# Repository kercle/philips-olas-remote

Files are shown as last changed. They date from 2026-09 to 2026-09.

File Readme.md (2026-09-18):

# Controller for Philips Olas Ceiling Fan

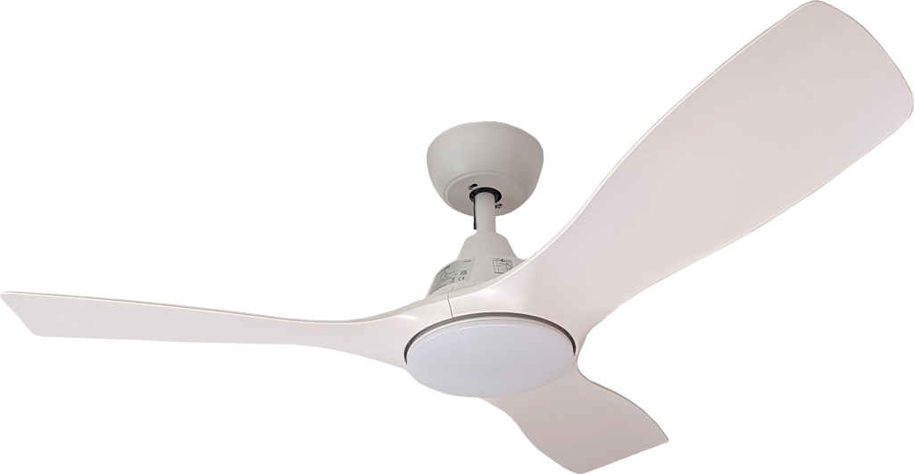
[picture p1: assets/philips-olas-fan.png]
Philips Olas ceiling fan


This little project aims at implementing the protocol of the [PHILIPS Olas ceiling fan](https://www.lighting.philips.at/consumer/p/deckenventilator-mit-beleuchtung-olas-deckenventilatorleuchte-32-w-ventilator-24-w-leuchte/8720169369993) for the purpose of home automation. The software was implemented for an ESP8266 micro-controller (NodeMCU) connected to a CC1101 module, but it can easily be adopted to other platforms.

> ⚖️ **Disclaimer:** This project is not affiliated, associated, authorized, or endorsed by Koninklijke Philips N.V. or any of its subsidiaries.

## Hardware

The remote can be prototyped on a simple breadboard. The circuit diagram using a NodeMCU (ESP8266) together with a CC1101 transceiver module (AYWHP) is given as follows:

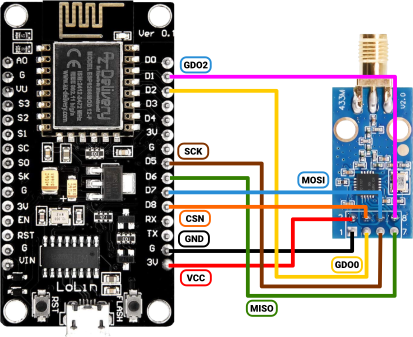
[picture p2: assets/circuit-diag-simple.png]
Circuit diagram for NodeMCU


## Protocol

The protocol was recorded using the firmware compiled from the `scanner` build-target. The firmware records permanently records high/low edges together with the time passed since the last detected edge. The protocol extraction was partly assisted by Claude.

### Physical layer

| Parameter | Value |
| :--- | :--- |
| Frequency | 434 MHz |
| Modulation | OOK (ASK) |
| Carrier ON | logical 1 in raw RF bitstream |
| Carrier OFF | logical 0 in raw RF bitstream |

### Packet timing

#### Sync marker (one per frame, before data bits)

| Field | RF State | Duration |
| :--- | :--- | :--- |
| Sync ON | Carrier ON | ~7400 µs  |
| Sync OFF | Carrier OFF  | ~1090 µs  |

#### Data bits

Each logical bit has a total period of ~1070 µs.

| Bit value | RF sequence | ON duration | OFF duration |
| :--- | :--- | :--- | :--- |
| **0** | short ON, long OFF | ~340 µs | ~730 µs |
| **1** | long ON, short OFF | ~730 µs | ~340 µs |

### Frame repetition

A single button press transmits **4–6 identical frames** back-to-back
(no gap between frames; the next frame's sync marker follows immediately
after the last data bit of the previous frame).

## Packet Structure

Each frame carries **41 bits**, transmitted MSB first.

```
Bits:
40 [ - - - - - - - - - - - - - - - - - - - - - - - - ] 17
     Fan ID: 24 bits
16 [ - - - - - - - - ]  9
     Command: 8 bits
8  [ - - - - - - - - ]  1
     Check: 8 bits
0  [ 0 ]  0
```

| Field | Bits  | Width | Description |
| :--- | :---- | :---- | :--- |
| Fan ID | 40–17 | 24 | Fixed hardware ID of the remote |
| Command | 16–9  | 8 | Upper 6 bits = function; lower 2 = sequence counter |
| Check | 8–1 | 8 | Integrity byte: `command XOR 0x5B` |
| Trailer | 0 | 1 | Always `0` |

The two sequence counter bits continuous decrement, i.e. assuming the current counter position is `2`, the next four packets will contain the counter position `1`, `0`, `3` and `2` in that order.

Frames captured in the same physical button press all carry the **same**
sequence value.

### Complete Command Table

All function codes below are the base value with sequence bits zeroed
(`functionCode & 0xFC`).

| Button | Function Code | Check (seq = 0) |
| :--- | :---: | :---: |
| Fan Off | `0x10` | `0x4B` |
| Fan Speed 1 | `0x40` | `0x1B` |
| Fan Speed 2 | `0xAC` | `0xF7` |
| Fan Speed 3 | `0x9C` | `0xC7` |
| Fan Speed 4 | `0x20` | `0x7B` |
| Fan Speed 5 | `0x80` | `0xDB` |
| Fan Speed 6 | `0x8C` | `0xD7` |
| Fan Forward/Reverse  | `0x50` | `0x0B` |
| Fan Sleep | `0x30` | `0x6B` |
| Fan Timer 1 h | `0x1C` | `0x47` |
| Fan Timer 3 h | `0x18` | `0x43` |
| Fan Timer 6 h | `0x14` | `0x4F` |
| Brightness Up | `0x70` | `0x2B` |
| Brightness Down | `0x28` | `0x73` |
| Warm White | `0x6C` | `0x37` |
| Day White | `0x84` | `0xDF` |
| Light On | `0x7C` | `0x27` |
| Light Off | `0xBC` | `0xE7` |

## Implementation details

In order to be able to send precise signals while not being disturbed by WiFi interrupts, we send frames via the CC1101's internal FIFO queue. From the experiments, we have seen that e.g. a zero is encoded as `~340 µs` high and `~730 µs` low. If we set the CC1101 transmission rate to `9323 bits/s` we note that every `107.262 µs` one bit is transferred from the FIFO queue. This allows us to control the timings of the signals we want to send:

| Level duration | Number of bit repetitions |
|:---|:- |
| 321.786 µs (Approximately 340 µs)  | 3 |
| 750.834 µs (Approximately 730 µs) | 7 |
| 7401.078 µs (Approximately 7400 µs) | 69 |
| 1072.62 µs (Approximately 1090 µs) | 10 |

These timings are close enough for the fan to register them. Since one frame contains 41 bits and each bit is encoded by 10 bits in the FIFO queue (`3 (short) + 7 (long)`) we need `69 (sync on) + 10 (sync off) + 41 (bits per frame) × 10 = 489` bits corresponding to 62 bytes in the FIFO queue. This means that we can send exactly one command to the fan via the FIFO queue without manual timing efforts.

This massively simplifies the communication, since now we don't have to worry about timing anymore.

## Web-interface

The firmware spawns a web server that can be used to access the fan controls via e.g. mobile devices within the local network. Note that at the time of writing, the web interface is not protected by any authentication.

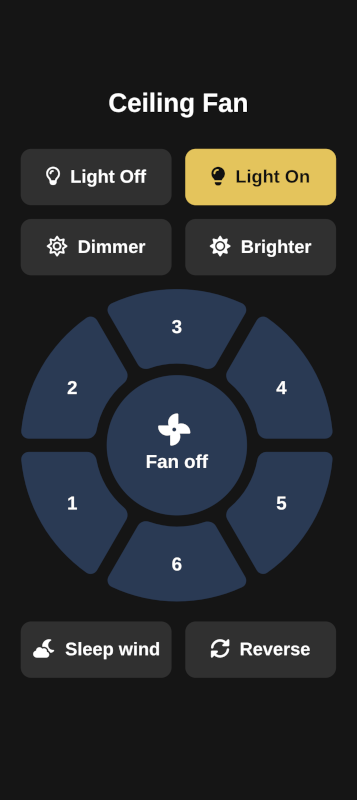
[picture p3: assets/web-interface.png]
Web interface


## Assembly

A small complete assembly is [provided in this repository](./assembly/design-a), complete with a 3D-printable case and a list of components needed for the assembly. The remote is powered via USB.

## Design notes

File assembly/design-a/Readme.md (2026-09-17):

# Design A

This is a simple designed based around a prototyping board, a NodeMcu Mini D1 Module (with Esp8266, but Esp32 should also work) and a CC1101 wireless module.
| Fully assembled | PCB in case |
|:-:|:-:|
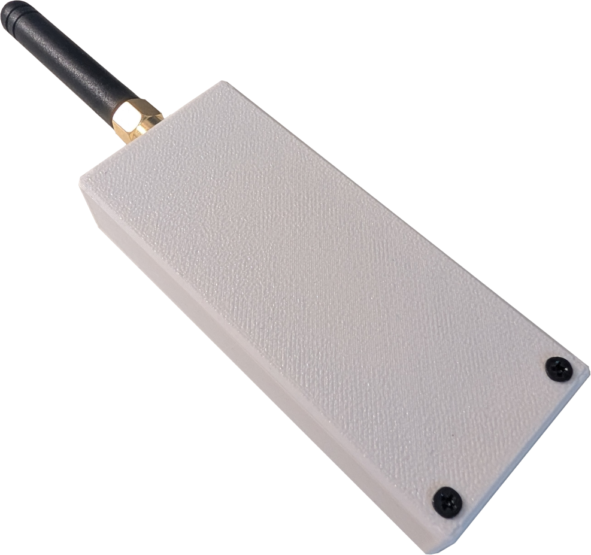
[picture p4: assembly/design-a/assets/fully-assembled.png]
Fully assembled
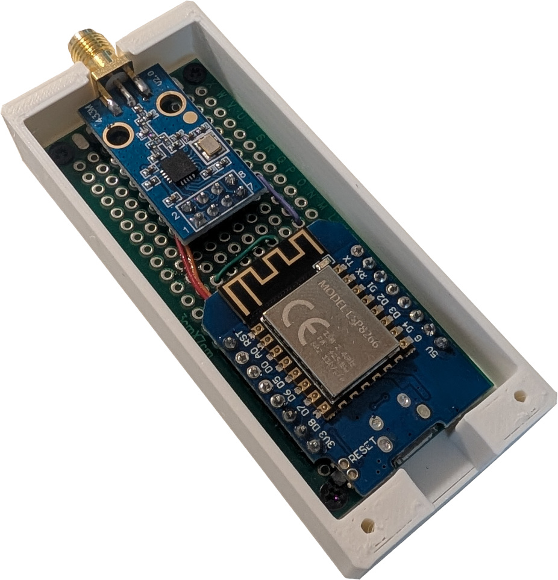
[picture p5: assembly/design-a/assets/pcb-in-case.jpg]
PCB in case
|  |  |

## BOM

| Component | Amount |
|:---|---:|
| 3x7 cm Prototyping circuit board (spacing 2.54 mm) | 1 |
| D1 Mini Nodemcu with ESP8266 | 1 |
| CC1101 Wireless module | 1 |
| 30 AWG Single Core | 
| M2x6 mm flathead screw | 3
| M2x10 mm flathead screw | 2
| 2.54 mm Male Header Pin (8 Pins) | 2

## Casing

The case can be 3D-printed on an FDM printer. I [designed in in OnShape](https://cad.onshape.com/documents/a087ceaa10398a32397951e5/w/04a95cbbb44f096dcf9181df/e/9778dcffe592d2e7d01ac76), but included the relevant STEP-files in this repository for convenience. The can be directly imported into slicers like OrcaSlicer.

## Notes

> Make sure to clip off the excess pins of the pin header on the back side of the PBC in order to make the controller board fit the case.

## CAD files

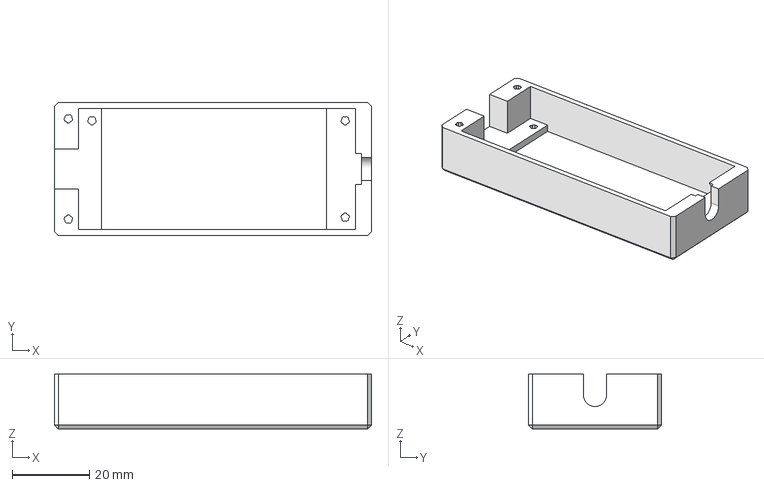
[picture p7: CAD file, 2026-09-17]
assembly/design-a/cad/case-body.step
82.0 x 34.4 x 14.2 mm

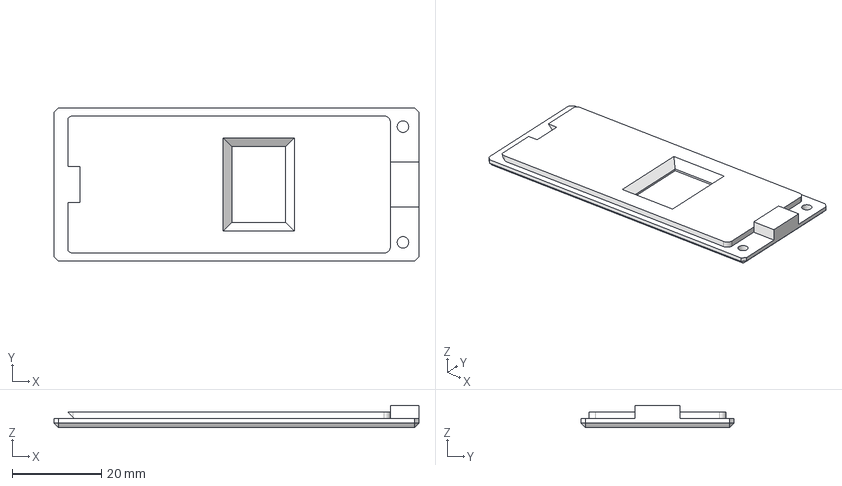
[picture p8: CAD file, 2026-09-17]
assembly/design-a/cad/case-lid.step
82.0 x 34.4 x 5.00 mm

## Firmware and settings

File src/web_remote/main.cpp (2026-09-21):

#include <ESP8266WiFi.h>
#include <ESP8266mDNS.h>

#include <config.h>
#include <secrets.h>

#include <olas/controller.h>
#include <olas_cc1101/radio.h>

#include <web_remote/web_server.h>

olas_cc1101::RadioTransmitterCC1101 radio(config::pin_cs, config::pin_gdo0, config::pin_gdo2);
olas::Controller controller(radio, secrets::fan_id);

void setup_wifi()
{
    WiFi.mode(WIFI_STA);
    WiFi.hostname(config::hostname);
    WiFi.begin(secrets::wifi_ssid, secrets::wifi_pass);
    MDNS.begin(config::hostname);

    Serial.print(F("Connecting to Wi-Fi"));
    while (WiFi.status() != WL_CONNECTED) {
        delay(500);
        Serial.print('.');
    }

    Serial.println(F(" OK"));
}

void setup_webserver()
{
    FanControllerWebServer::get_instance().initialize();

    Serial.print(F("Web server ready.\nGo to http://"));
    Serial.print(WiFi.localIP());
    Serial.print(F("/ or http://"));
    Serial.print(config::hostname);
    Serial.println(".local/ to access the dashboard.");
}

void setup()
{
    Serial.begin(115200);
    delay(500);

    Serial.println(F("\nPhilips Ceiling Fan Controller"));

    setup_wifi();
    setup_webserver();

    auto res = radio.initialize();
    if (res.is_err()) {
        Serial.print(F("Radio transmitter initialization failed: "));
        Serial.println(res.code());
        delay(5000);
        ESP.reset();
    }
}

void loop()
{
    static auto fan_state = controller.get_state();

    FanControllerWebServer& web_server = FanControllerWebServer::get_instance();

    auto task = web_server.take_task();
    if (task.has_value()) {
        (*task)(controller);
    }

    controller.handle_received_data();

    if (fan_state != controller.get_state()) {
        fan_state = controller.get_state();
        Serial.print("Light: ");
        Serial.println(fan_state.light);
        Serial.print("Fan: ");
        Serial.println(fan_state.fan);
        Serial.print("Reversed: ");
        Serial.println(fan_state.reversed);
    }

    web_server.handle_client();
    MDNS.update();
    yield();
}

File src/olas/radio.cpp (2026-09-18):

#include <olas/radio.h>

namespace olas {

RadioTransmitterResult::RadioTransmitterResult(bool _ok, int16_t _code)
    : _ok(_ok)
    , _code(_code)
{
}

RadioTransmitterResult RadioTransmitterResult::ok()
{
    return RadioTransmitterResult(true, 0);
}

RadioTransmitterResult RadioTransmitterResult::err(int16_t code)
{
    return RadioTransmitterResult(false, code);
}

bool RadioTransmitterResult::is_err() const
{
    return !_ok;
}

bool RadioTransmitterResult::is_ok() const
{
    return _ok;
}

int16_t RadioTransmitterResult::code() const
{
    return _code;
}

RadioTransmitter::RadioTransmitter(uint8_t pin_cs, uint8_t pin_gdo0, uint8_t pin_gdo2)
    : frame_builder(nullptr)
    , radio_module(pin_cs, pin_gdo0, RADIOLIB_NC, pin_gdo2)
    , radio(&radio_module)
    , rx_state(pin_gdo0)
    , initialized(false)
    , receiving(false)
{
}

RadioTransmitterResult RadioTransmitter::initialize(FrameBuilder* frame_builder)
{
    if (initialized) {
        return RadioTransmitterResult::ok();
    }

    this->frame_builder = frame_builder;

    int16_t state = 0;

    state = radio.begin(config::rf_frequency_mhz, config::raw_bitrate_kbps, 5.0, 100.0, 10, 16);
    if (state != RADIOLIB_ERR_NONE) {
        return RadioTransmitterResult::err(state);
    }

    state = radio.setOOK(true);
    if (state != RADIOLIB_ERR_NONE) {
        return RadioTransmitterResult::err(state);
    }

    //    We want the FIFO bytes to be transmitted literally.
    //    Promiscuous mode is useful here even though we're
    //    transmitting rather than receiving: in the current
    //    RadioLib CC1101 implementation it disables automatic
    //    sync-word insertion and disables CRC.
    state = radio.setPromiscuousMode(true);
    if (state != RADIOLIB_ERR_NONE) {
        return RadioTransmitterResult::err(state);
    }

    // No address byte.
    state = radio.disableAddressFiltering();
    if (state != RADIOLIB_ERR_NONE) {
        return RadioTransmitterResult::err(state);
    }

    auto ret = start_receiving();
    if (ret.is_err()) {
        return ret;
    }

    initialized = true;
    return RadioTransmitterResult::ok();
}

RadioTransmitterResult RadioTransmitter::start_receiving()
{
    // We don't have to check if we are initialized here,
    // since start_receiving is called by initialize
    // and transmit_burst stops and starts receiving again.

    if (receiving) {
        return RadioTransmitterResult::ok();
    }

    int16_t state = radio.receiveDirectAsync();
    if (state != RADIOLIB_ERR_NONE) {
        return RadioTransmitterResult::err(state);
    }

    pinMode(radio_module.getGpio(), INPUT);
    attachInterruptArg(
        digitalPinToInterrupt(radio_module.getIrq()),
        RadioRxState::handle_edge,
        static_cast<void*>(&rx_state),
        CHANGE);

    receiving = true;
    return RadioTransmitterResult::ok();
}

RadioTransmitterResult RadioTransmitter::stop_receiving()
{
    if (!receiving) {
        return RadioTransmitterResult::ok();
    }

    detachInterrupt(digitalPinToInterrupt(radio_module.getIrq()));

    int16_t state = radio.finishReceive();
    if (state != RADIOLIB_ERR_NONE) {
        return RadioTransmitterResult::err(state);
    }

    receiving = false;
    return RadioTransmitterResult::ok();
}

bool RadioTransmitter::is_initialized() const
{
    return initialized;
}

void RadioTransmitter::encode_bit(WaveformBuffer& waveform, bool bit)
{
    // TODO: don't fail silently when waveform overfills
    // in particular if this code is reused for other
    // appliances.

    if (bit) {
        waveform.push_repeated(true, config::long_bits);
        waveform.push_repeated(false, config::short_bits);
    } else {
        waveform.push_repeated(true, config::short_bits);
        waveform.push_repeated(false, config::long_bits);
    }
}

void RadioTransmitter::encode_sync_signal(WaveformBuffer& waveform)
{
    // TODO: don't fail silently when waveform overfills
    // in particular if this code is reused for other
    // appliances.

    waveform.push_repeated(true, config::sync_on_bits);
    waveform.push_repeated(false, config::sync_off_bits);
}

void RadioTransmitter::build_waveform(WaveformBuffer& waveform, Command cmd)
{
    encode_sync_signal(waveform);
    auto frame = frame_builder->build(cmd);

    for (uint8_t i = 0; i < frame.bit_size(); ++i) {
        encode_bit(waveform, frame.get_frame_bit(i));
    }
}

bool RadioTransmitter::configure_transmit_mode()
{
    int16_t state = radio.packetMode();
    if (state != RADIOLIB_ERR_NONE) {
        return false;
    }

    state = radio.setPromiscuousMode(true);
    if (state != RADIOLIB_ERR_NONE) {
        return false;
    }

    /*
       Fixed packet length means there is no automatically
       transmitted length byte.

       The entire over-the-air payload is our 62-byte waveform.
    */
    state = radio.fixedPacketLengthMode(WaveformBuffer::capacity_bytes());
    return state == RADIOLIB_ERR_NONE;
}

bool RadioTransmitter::transmit_waveform(WaveformBuffer& waveform)
{
    int16_t state = radio.startTransmit(
        waveform.get_raw(),
        WaveformBuffer::capacity_bytes());

    if (state != RADIOLIB_ERR_NONE) {
        return false;
    }

    // Safety delay: 62 bytes * 8 = 496 bits
    // 496 / 9323 bits/s ~= 53.2 ms
    // This mean that if we wait 57 ms, we cannot flood the CC1101
    // With frames essentially transmitting garbage.
    // TODO: maybe something more generalizable to async envs
    // e.g. a function that checks if this time has passed and
    // lets the caller decide if to delay or not.
    // TODO: impl better solution later.
    delay(57);

    // CC1101 should now be in IDLE state.
    state = radio.finishTransmit();
    if (state != RADIOLIB_ERR_NONE) {
        return false;
    }

    return true;
}

bool RadioTransmitter::transmit(Command cmd)
{
    return transmit_bursts(cmd, 1);
}

bool RadioTransmitter::transmit_bursts(Command cmd, uint8_t repeats)
{
    if (!is_initialized() || !repeats) {
        return false;
    }

    WaveformBuffer waveform;
    build_waveform(waveform, cmd);

    if (stop_receiving().is_err()) {
        // If stop receiving didn't work
        // try to start it. In any case,
        // function wasn't successful.
        start_receiving();
        return false;
    }

    bool success = configure_transmit_mode();

    if (success) {
        for (uint8_t i = 0; i < repeats; ++i) {
            if (!transmit_waveform(waveform)) {
                success = false;
                break;
            }
        }
    }

    if (start_receiving().is_err()) {
        return false;
    }

    if (!success) {
        return false;
    }

    frame_builder->advance_frame_counter();
    return true;
}
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

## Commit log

2026-09-13 Added ceiling fan image.
2026-09-13 Implement frame builder.
2026-09-14 Wrap frame builder and radio transmitter in controller class for better ergonomics.
2026-09-14 Add fan speed control on web-server.
2026-09-14 Fix: send fan_off command in /api/fan/off endpoint.
2026-09-14 Design fan control UI.
2026-09-14 Attach API calls to fan controls.
2026-09-14 Tighten UI and add brightness control as well as sleep wind and direction reversal.
    [main.cpp]
2026-09-14 Fix bound checking in Frame::get_frame_bit.
2026-09-14 Pin Command enum to uint8_t type.
2026-09-14 Also print the mDNS based URL when the service comes up.
2026-09-16 Use my own photo of fan in readme.
2026-09-17 Added assembly and more info in the readme.
    [case-body.step, case-lid.step]
2026-09-17 Improve brightness and contrast of olas fan image.
2026-09-17 Added PCB in case image.
2026-09-18 Implement receiver alongside transmitter.
    The receiver listens in on signals whenever there is nothing to transmit.
    This allows us to keep track of the state even with multiple remotes.
    This state can be published via MQTT for integration into e.g. Home Assistent.
2026-09-18 Do not git-track subset font files as they are derived from the full fonts.
2026-09-18 Fix: Detach ISR from correct pin.
    [radio.cpp]
2026-09-20 Drain all pending received frames in `handle_received_data`.
2026-09-20 Write a simple test for testing frame parsing.
2026-09-21 Fix: in `fan_on` break from switch.
2026-09-21 Fix: in `handle_receive_frame`, do not return when device id does not match.
2026-09-21 Update fan state in controller API.
